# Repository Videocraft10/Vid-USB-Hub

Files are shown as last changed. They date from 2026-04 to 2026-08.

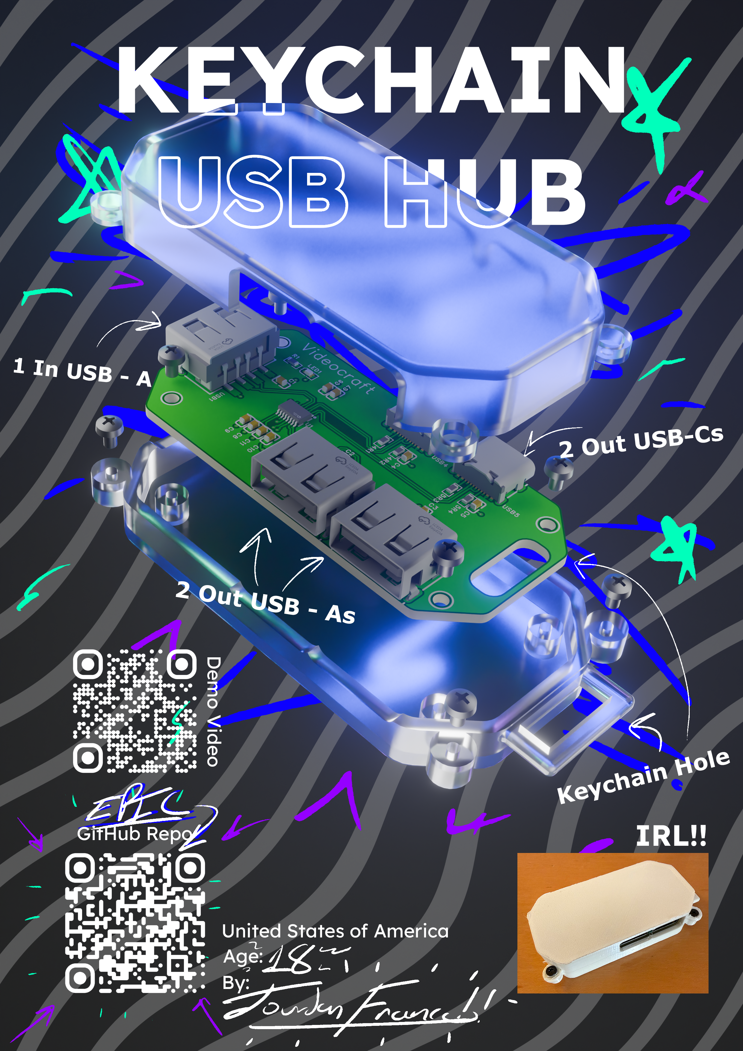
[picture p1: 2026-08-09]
Promo Files/Exports/Videocraft USB Hub v2 Zine BUILD VID.png

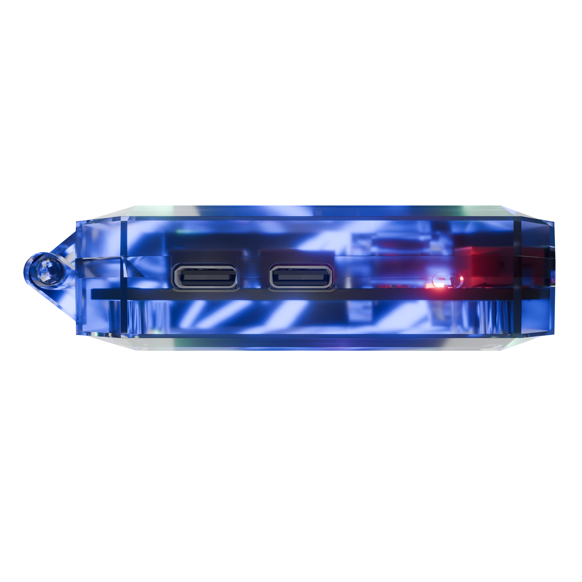
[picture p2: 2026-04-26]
Promo Files/Exports/BigEpicUSBHubMainv2 4k.png

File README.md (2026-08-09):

# USB Hub: Videocraft Edition
USB Hub Main v2
A custom made USB Hub with some cool little features created for Hack Club Fallout.  

*picure above is of v1 case*

## Features
Videocraft USB Hub v2 Zine BUILD VID

1. USB-A Input with 4 output USBs (2 A and 2 C)
2. Cool Keychain hole so you can take your hub around you with style :)
3. Easy to open, 3D printed case so you can admire the PCB
4. Red power LED to indicate when power is flowing though (great to make sure it ain't broke)
5. Secured by 4 easy to remove M2 screws if you want to update the case with a different PCB with the same silhouette

## Why??
I created this project to expand my knowlage on how hardware works on a fundemental level and how it is created, through sourcing materials, and designing the PCB. Additionally I wanted to add my own custom spin on the classic USB Hub by adding some cool fetures that I would appreicate and use.

## The PCB
The PCB for this project was created within EasyEDA for easy parts and footprint integration.

**The Schematic:**


**The Circuit Board:**

Front:


Back:


Picture of the PCB IRL!!



## The Case (v1)
This case was designed using Blender, I choose this over CAD options AT FIRST due to my extensive knowledge and experience in the software.

**Full case**

*This case features a key chain hole and a LED Hole*

**Bottom**



**Top**



**Case open with PCB Inside**

*This case also features a open swinging design to easily open the case though the 3D printed latch to see inside*

## The Case TWO!! (v2)
After designing the case in blender, due to the requirement of having CAD files in the GitHub, I created a second version of the case using Fusion 360!

**Full Case**


**Bottom**


**Top**


**Case with PCB**


**Case Split Up**



## IRL!!




## PCB BOM
*Amount used is for 2 USB Hubs + Price quotes though EasyEDA PCBA*

| Item | JLCPCB # | Single Cost | Amount Used | Fees | Total Price |
| --- | --- | --- | --- | --- | --- |
| 	<ins>USB Hub Chip</ins> | [C2684433](https://jlcpcb.com/partdetail/CoreChips-SL21s/C2684433) | $0.2245 | 2 | Forced to order 5 minimum | $1.1225|
| Resistor 5.1k | [C23186](https://jlcpcb.com/partdetail/23913-0603WAF5101T5E/C23186) | $0.0016 | 8 | None | $0.0128 |
| Capacitors 1uF | [C15849](https://jlcpcb.com/partdetail/16531-CL10A105KB8NNNC/C15849) | $0.0078 | 16 | None | $0.01248 |
| Capacitors 100nF | [C14663](https://jlcpcb.com/partdetail/YAGEO-CC0603KRX7R9BB104/C14663) | $0.003 | 6 | None | $0.018 |
| Power LED | [C2286](https://jlcpcb.com/partdetail/Hubei_KENTOElec-KT0603R/C2286) | $0.0066 | 2 | None | $0.0132 |
| Resistor 330 | [C23138](https://jlcpcb.com/partdetail/23865-0603WAF3300T5E/C23138) | $0.0016 | 2 | None | $0.0032 |
| <ins>Type-A USBs</ins> | [C668591](https://jlcpcb.com/partdetail/SHOUHAN-10_0_QHHTZB63/C668591) | $0.0662 | 6 | Difficult Component Fee + $0.03 per. Plus Order must be a even number, forced to buy 8 (3 for 1 PCB = not even. Forced 4 for one = 8 for both) | $0.5296 |
| <ins>Type-C USBs</ins> | [C2765186](https://jlcpcb.com/partdetail/SHOUHAN-TYPE_C_16PIN_2MD_073/C2765186) | $0.066 | 4 | Forced to buy 5 | $0.33 |
| **PCB Price** | -------- | **PCBA Price + Fees** | **NOTES** | -------- | -------- |
| $2 | -------- | Setup Fee | -------- | -------- | $8.12 |
| -------- | -------- | Stencil | -------- | -------- | $1.52 |
| -------- | -------- | Components | -------- | -------- | $2.15 |
| -------- | -------- | Extended Components Fee | $3.04 per Extended Component (Underlined components are Extended)| -------- | $9.12 |
| -------- | -------- | SMT Assembly | $0.0016 Fee per solder point | -------- | $0.44 |
| -------- | -------- | Special Componet Fee (Type-A USB Difficult fee) | -------- | -------- | $0.24 |
| -------- | -------- | Nitrogen Reflow Soldering | -------- | -------- | $0.85 |
| Total Cost for PCB + 2 PCBA | -------- | -------- | -------- | -------- | $24.44 |
| Shipping Fee | -------- | -------- | -------- | -------- | $9.25 |
| Sales Tax | -------- | -------- | -------- | -------- | $2.23 |
| Grand Total | PCB (5) + PCBA (2) + Shipping + Tax | -------- | -------- | -------- | $35.92 |

## Build BOM

| Item | Discripton | Notes | Cost/Amount Used |
| --- | --- | --- | --- |
| 3D Printer PLA | Generic 3D printer PLA. Requires a 3D printer to use | Paid $8.34 for 1 kg | Aproxx 14g of filament = $0.12 |
| M2 x 3mm Screws | -------- | 4 Required for case v1, 8 required for case v2 | $4.28 [here](https://www.amazon.com/gp/product/B0B1Q9QQ7F?smid=A1BQWGBLWM4VYT&th=1) | 
| ---------- | ---------- | ---------- | ---------- | ---------- | ---------- |
| Total | ---------- | ---------- | ---------- | ---------- | $4.40 |

***GRAND TOTAL*** = $40.32

## How to use!
Pretty simple! Plug in a device, like a phone or computer, and you can now plug four USB accessoies though that one USB port!

## How to make one yourself!
*If you have no intention of modifying the case or PCB and you have a 3D printer, here are the steps to follow:*

1. Download your preferred case from the [Ready to Print](https://github.com/Videocraft10/Vid-USB-Hub/tree/main/Case%20Files/Ready%20to%20Print%20Files) folder. Please note that the only case that is 100% polished and updated will always be [V2 Case Files](https://github.com/Videocraft10/Vid-USB-Hub/tree/main/Case%20Files/Ready%20to%20Print%20Files/V2%20Case%20Files) Once downloaded (click the download button on the top right), open it in your 3D printer slicer of choice and export. I will be printing in a generic PLA on an Ender 3 Pro 3D printer, using the Super Quality preset, with tree supports enabled in the Cura Slicer settings.
2. Once you have the 3D print going, download the EasyEDA PCB files from the [PCB](https://github.com/Videocraft10/Vid-USB-Hub/tree/main/PCB%20Files) folder in the GitHub. Please note that EasyEDA files are not supported on KiCad, but you might be able to get them to work with some workarounds if you really want to.
3. Import to EasyEDA and click Order.
4. It is recommended to select the PCB Assembly option to get it pre-assembled. I recommend getting 2 assembled.
6. There you go! Once your PCB arrives, smack it into the case and secure it with M2 screws in the 4 corners. (if you did case v2 then also secure the case shut with 4 more m2 screws!)
7. You are now a proud owner of the Videocraft USB Hub :)
P.S. If you dont want to use EasyEDA I have also included the Garber File export too! You can find it [here!](https://github.com/Videocraft10/Vid-USB-Hub/blob/main/PCB%20Files/Gerber_VidUSBHUB.zip)

*If you **DO** have intentions of modifying the case or PCB, here are the steps to follow:*
1. All Blender files, including promotional files, are [here](https://github.com/Videocraft10/Vid-USB-Hub/tree/main/Promo%20Files).
2. Blender files were created in Blender 5.1.1.
3. CAD Files are ONLY avalable for Case v2 (closed, no opening mechanism)
4. CAD Files where created in Fusion 360, with .f3z .obj and .step files avalable
5. CAD files are located [here](https://github.com/Videocraft10/Vid-USB-Hub/tree/main/Case%20Files/CAD%20Files%20(v2))
6. Download the EasyEDA files from above in the [PCB](https://github.com/Videocraft10/Vid-USB-Hub/tree/main/PCB%20Files) folder in the GitHub.
7. Import into EasyEDA and modify to your heart's content!

## Software Used
1. EasyEDA
2. Blender
3. Autodesk Fusion
4. Adobe Photoshop
5. Adobe Premiere Pro

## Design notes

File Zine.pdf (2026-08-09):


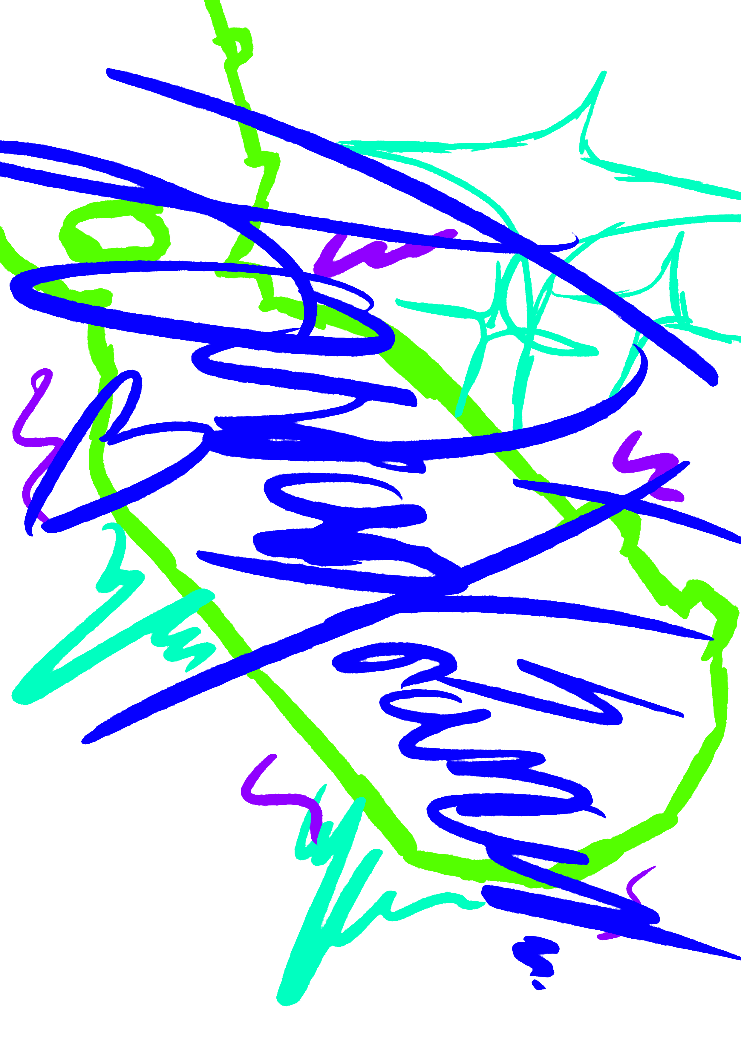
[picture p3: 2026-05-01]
Promo Files/Exports/Videocraft USB Hub Zine Grafiti.png

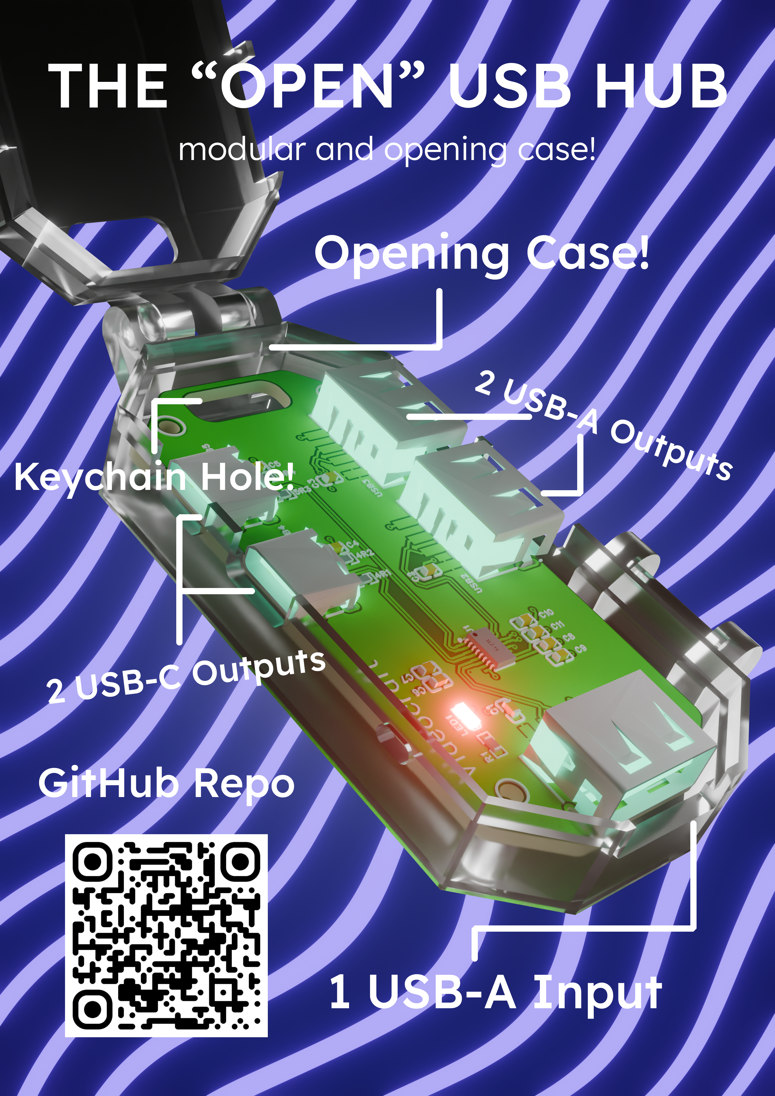
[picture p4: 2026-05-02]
Promo Files/Exports/Videocraft USB Hub Zine v2.png

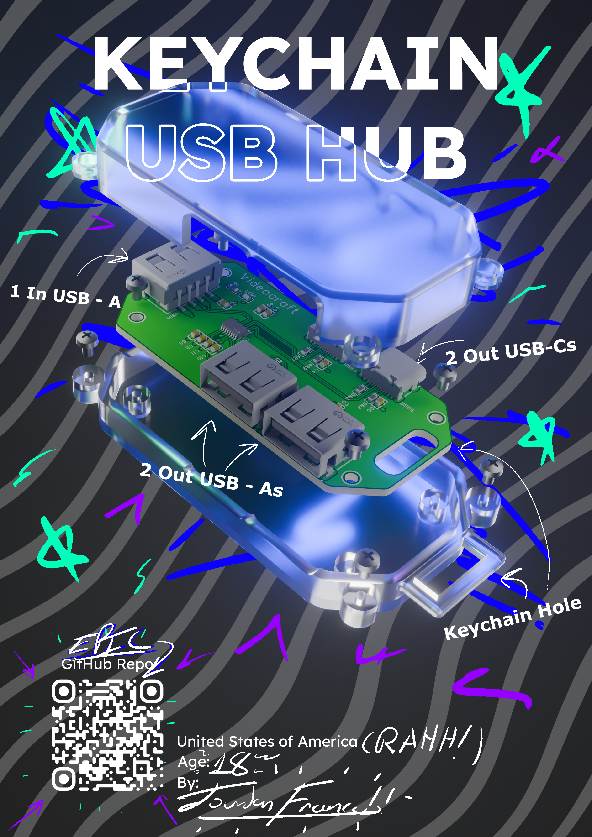
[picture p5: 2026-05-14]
Promo Files/Exports/Videocraft USB Hub Zine v5.png

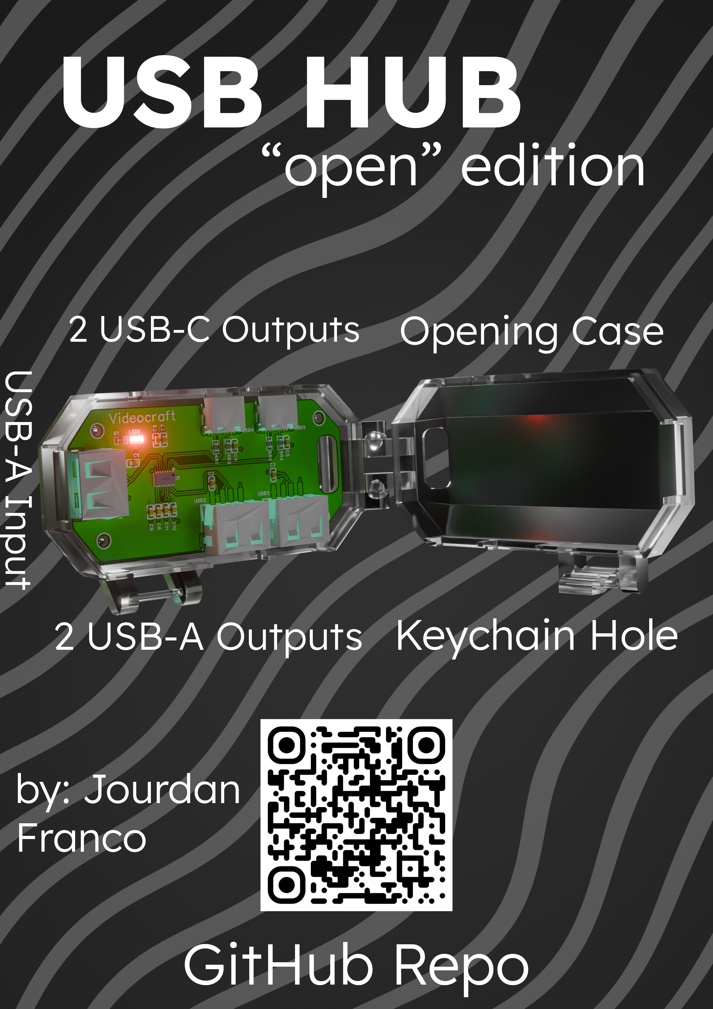
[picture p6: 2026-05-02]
Promo Files/Exports/Videocraft USB Hub Zine v3.png

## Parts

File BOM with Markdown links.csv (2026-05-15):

PCB BOM
Item | JLCPCB # | Single Cost | Amount Used | Fees | Total Price
USB Hub Chip | [C2684433](https://jlcpcb.com/partdetail/CoreChips-SL21s/C2684433) | $0.22 | 2 | Forced to order 5 minimum | $1.12
Resistor 5.1k | [C23186](https://jlcpcb.com/partdetail/23913-0603WAF5101T5E/C23186) | $0.00 | 8 | None | $0.01
Capacitors 1uF | [C15849](https://jlcpcb.com/partdetail/16531-CL10A105KB8NNNC/C15849) | $0.01 | 16 | None | $0.01
Capacitors 100nF | [C14663](https://jlcpcb.com/partdetail/YAGEO-CC0603KRX7R9BB104/C14663) | $0.00 | 6 | None | $0.02
Power LED | [C2286](https://jlcpcb.com/partdetail/Hubei_KENTOElec-KT0603R/C2286) | $0.01 | 2 | None | $0.01
Resistor 330 | [C23138](https://jlcpcb.com/partdetail/23865-0603WAF3300T5E/C23138) | $0.00 | 2 | None | $0.00
Type-A USBs | [C668591](https://jlcpcb.com/partdetail/SHOUHAN-10_0_QHHTZB63/C668591) | $0.07 | 6 | Difficult Component Fee + $0.03 per. Plus Order must be a even number, forced to buy 8 (3 for 1 PCB = not even. Forced 4 for one = 8 for both) | $0.53
Type-C USBs | [C2765186](https://jlcpcb.com/partdetail/SHOUHAN-TYPE_C_16PIN_2MD_073/C2765186) | $0.07 | 4 | Forced to buy 5 | $0.33
PCB Price |  | PCBA Price + Fees | NOTES
$2 |  | Setup Fee |  |  | $8.12
 |  | Stencil |  |  | $1.52
 |  | Components |  |  | $2.15
 |  | Extended Components Fee | $3.04 per Extended Component (Underlined components are Extended) |  | $9.12
 |  | SMT Assembly | $0.0016 Fee per solder point |  | $0.44
 |  | Special Componet Fee (Type-A USB Difficult fee) |  |  | $0.24
 |  | Nitrogen Reflow Soldering |  |  | $0.85
Total Cost for PCB + 2 PCBA |  |  |  |  | $24.44
Shipping Fee |  |  |  |  | $9.25
Sales Tax |  |  |  |  | $2.23
Grand Total | PCB (5) + PCBA (2) + Shipping + Tax |  |  |  | $35.92
## Build BOM [WIP]
Item | Discripton | Notes | Cost/Amount Used
3D Printer PLA | Generic 3D printer PLA. Requires a 3D printer to use | Paid $8.34 for 1 kg | Aproxx 14g of filament = $0.12
M2 x 3mm Screws |  | 4 Required for case v1, 8 required for case v2 | [$0.80](https://www.moddiy.com/products/1262/M2.0-x-3mm-Black-Screws-CM2X3X4.html)

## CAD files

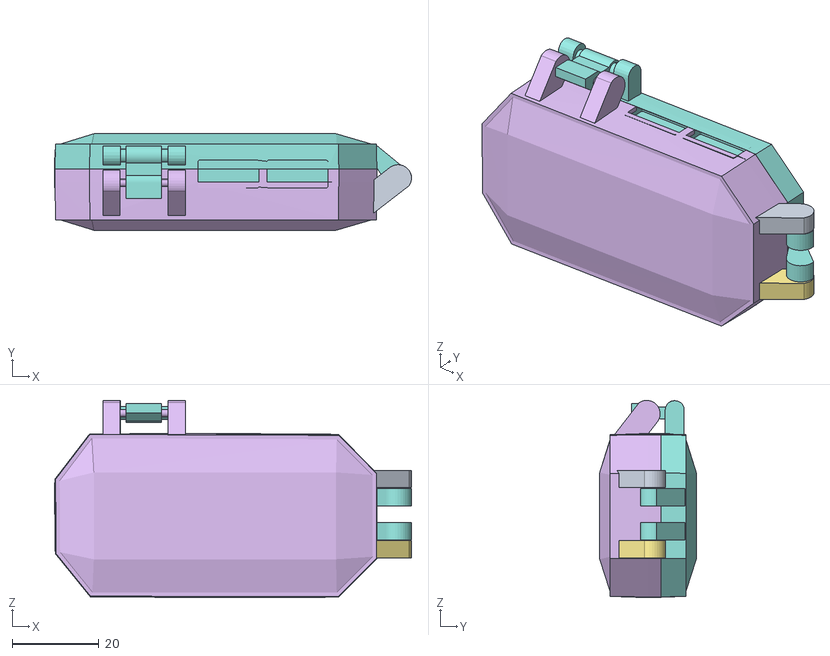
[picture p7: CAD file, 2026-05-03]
Case Files/Blender Files (v0)/Videocraft USB Hub v0 Case All Componets.obj
82.2 x 22.2 x 45.4
VidUSBHubv0
Scew
Scew.001
Scew.002
Scew.003
CaseBot
LatchR.001
LatchL.002
LatchR.002

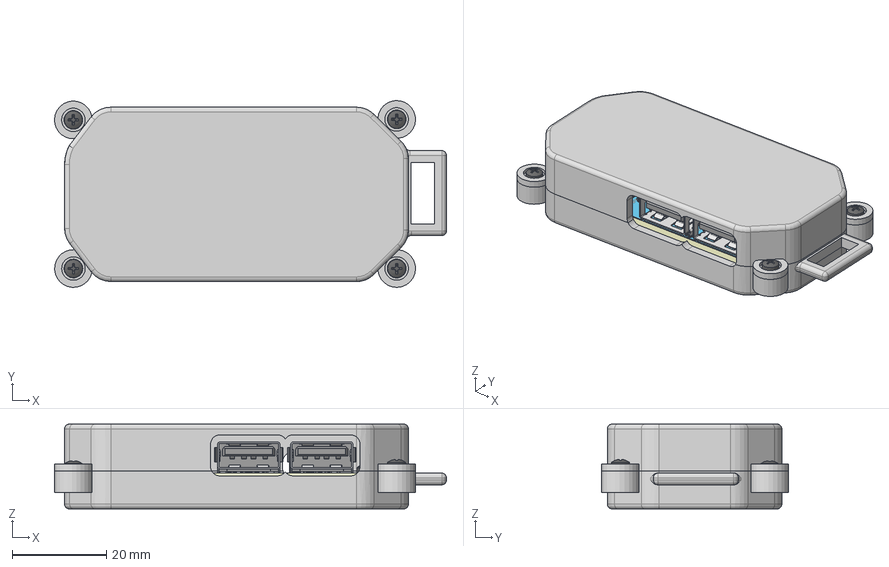
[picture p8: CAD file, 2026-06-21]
Case Files/CAD Files (v2)/Videocraft USB Hub v2 CAD.step
83.1 x 39.6 x 18.0 mm
DIN 7985 - M2x3-H H Steel 4.6 Zinc x 7
DIN 7985 - M2x3-H H Steel 4.6 Plain

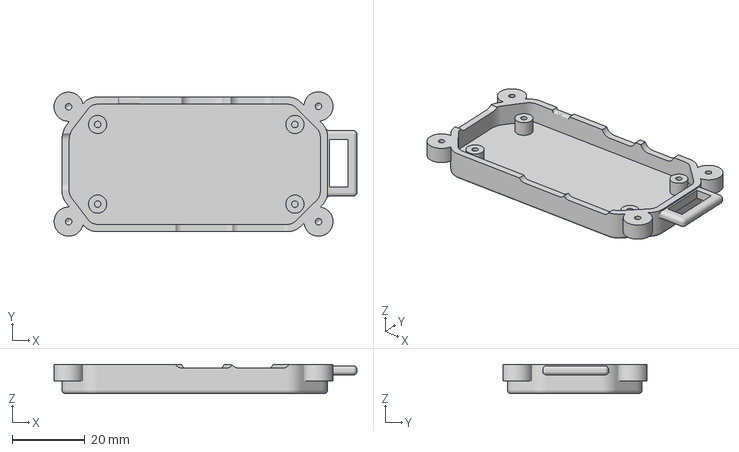
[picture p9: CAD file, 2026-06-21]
Case Files/Ready to Print Files/V2 Case Files/Closed Videocraft USB Case Bottom v2.3mf
83.1 x 39.6 x 8.00 mm

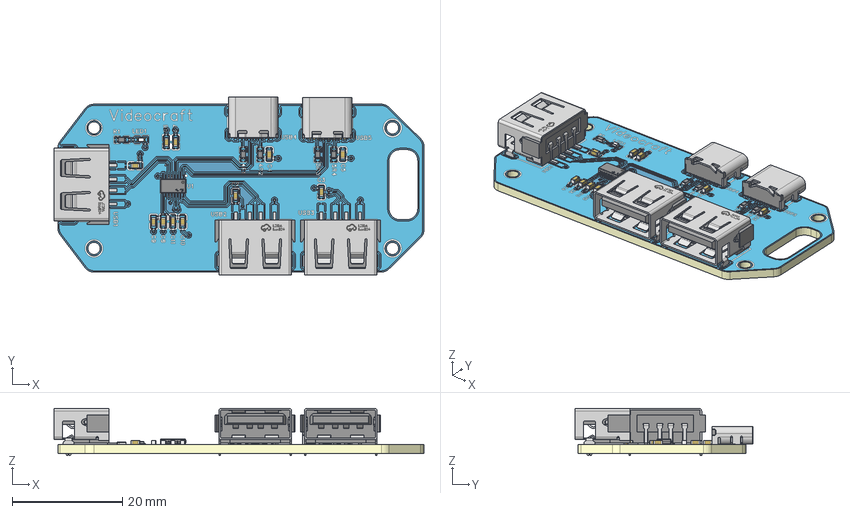
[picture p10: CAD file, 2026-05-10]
PCB Files/Videocraft USB Hub CAD PCB.step
67.1 x 32.3 x 8.60 mm
Board~aYtN
TopCopper~aYtN
BottomCopper~aYtN
TopSilkscreen~aYtN
BottomSilkscreen~aYtN
TopFpcStiffener~aYtN
BottomFpcStiffener~aYtN
LED0603-RD~LED0603-RD~aYtN
R0603~R0603~aYtN x 5
C0603~C0603_L1.6-W0.8-H0.8~aYtN x 11
USB-C-SMD_TYPE-C-6PIN-2MD-073~USB-C-SMD_TYPE-C-6PIN-2MD-073~aYtN x 2
SSOP-16_L4.6-W2.6-P0.53-LS4.0-BL~SSOP-16_L4.6-W2.6-P0.53-LS4.0-BL~aYtN
USB-A-TH_10.0QHHTZB6.3~USB-A-TH_10.0QHHTZB6.3~aYtN x 3

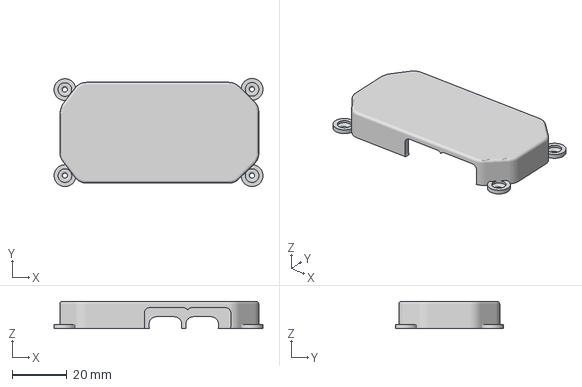
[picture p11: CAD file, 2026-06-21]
Case Files/Ready to Print Files/V2 Case Files/Closed Videocraft USB Case Top v2.3mf
76.5 x 39.6 x 10.0 mm

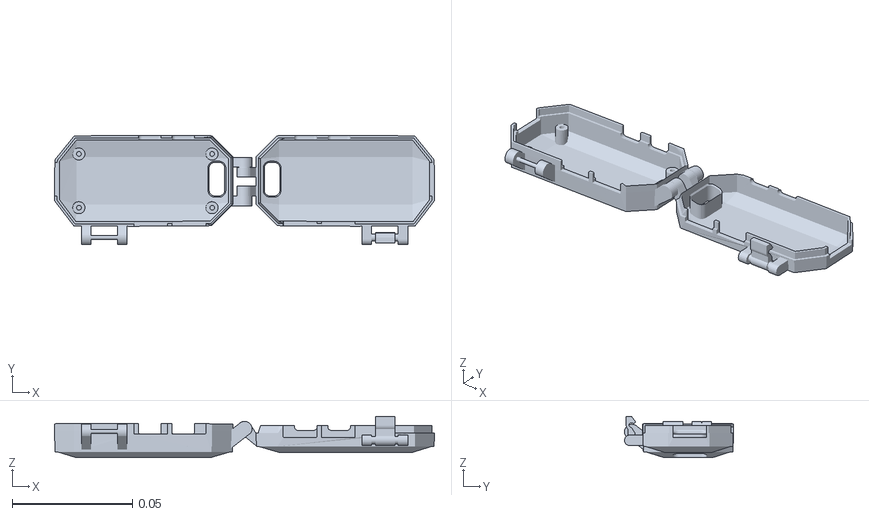
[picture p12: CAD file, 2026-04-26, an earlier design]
Case Files/Ready to Print Files/V0 Case Files/Videocraft USB Hub v0 Case Keyhole_Print.stl
0.158 x 0.0454 x 0.0172

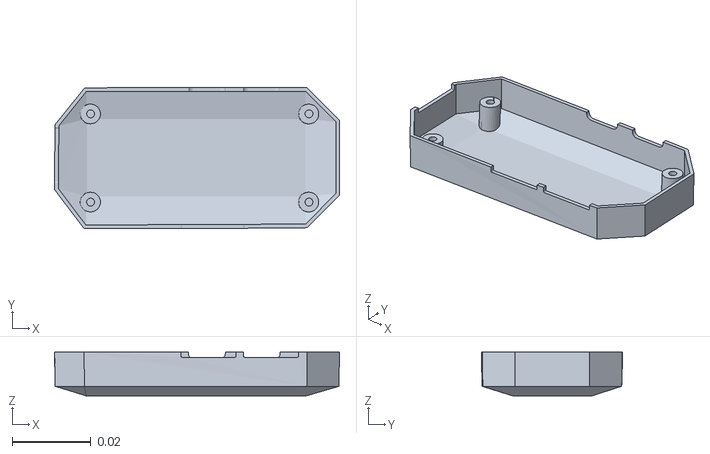
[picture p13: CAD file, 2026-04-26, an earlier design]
Case Files/Ready to Print Files/V0 Case Files/NO LATCH Bottom Videocraft USB Hub v0 Case.stl
0.0723 x 0.0358 x 0.0111

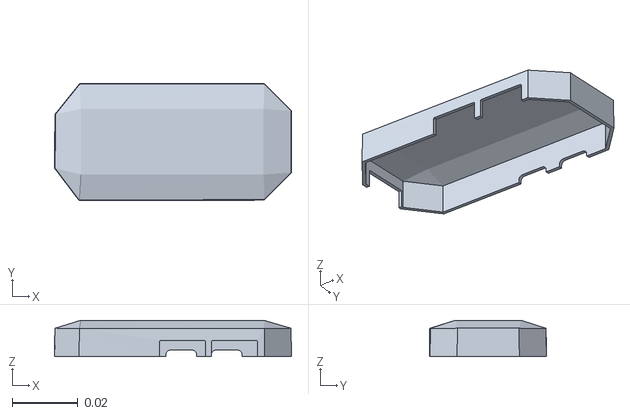
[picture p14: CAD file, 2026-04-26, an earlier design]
Case Files/Ready to Print Files/V0 Case Files/NO LATCH Top Videocraft USB Hub v0 Case.stl
0.0723 x 0.0358 x 0.0111

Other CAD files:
Case Files/Ready to Print Files/V0 Case Files/Videocraft USB Hub v0 Case_Print.stl
Case Files/Ready to Print Files/V0 Case Files/Videocraft USB Hub v0 Case Keyhole+LED Hole_Print.stl
Case Files/Blender Files (v0)/Videocraft USB Hub v0 Case All Componets.blend
Case Files/Blender Files (v0)/Videocraft USB Hub v0 Case Pre Lock.blend
Case Files/Blender Files (v0)/Videocraft USB Hub v0 Case Print Ready Keyhole.blend
Case Files/Blender Files (v0)/Videocraft USB Hub v0 Case.blend
Case Files/CAD Files (v2)/Videocraft USB Hub v2 CAD.f3z
Case Files/CAD Files (v2)/Videocraft USB Hub v2 CAD.obj
Promo Files/Blender Files/Backgound.blend
Promo Files/Blender Files/Videocraft USB Hub v0 Case Promo Zine View 2.blend
Promo Files/Blender Files/Videocraft USB Hub v0 Case Promo Zine View 3.blend
Promo Files/Blender Files/Videocraft USB Hub v0 Case Promo Zine View 4.blend
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

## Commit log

2026-04-25 Add BOM section with component costs and details
    Added Bill of Materials (BOM) for USB Hub components and pricing details.
2026-04-25 Revise README with features and BOM details
    Updated the README to enhance the description and add features and BOM sections.
2026-04-26 Expand README with project details and instructions
    Added sections on project motivation, PCB details, case design, and BOM for creating a USB hub.
2026-04-26 Added Development Files
    [NO LATCH Bottom Videocraft USB Hub v0 Case (2).stl, NO LATCH Top Videocraft USB Hub v0 Case (1).stl, Videocraft USB Hub v0 Case Keyhole+LED Hole_Print.stl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]
2026-04-26 Update README with DIY instructions for USB Hub
    Added detailed instructions for creating the Videocraft USB Hub, including 3D printing and PCB assembly steps.
2026-04-27 Fix typos and enhance clarity in README instructions
    Correct typos and improve clarity in instructions for 3D printing and PCB assembly.
2026-04-27 Added BOM CSV file
    [Videocraft_USB_Hub_BOM.csv]
2026-04-27 Reorganized folders
    [NO LATCH Bottom Videocraft USB Hub v0 Case (2).stl, NO LATCH Top Videocraft USB Hub v0 Case (1).stl, Videocraft USB Hub v0 Case Keyhole+LED Hole_Print.stl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]
2026-04-29 Fix links and update folder names in README
    Updated links and folder names for case and PCB files in the README.
2026-05-01 Zine Work
    [Backgound.blend, Videocraft USB Hub v0 Case Promo Zine.blend]
2026-05-02 Created more zine prototypes
    [Videocraft USB Hub v0 Case Promo Zine View 2.blend, Videocraft USB Hub v0 Case Promo Zine.blend]
2026-05-03 MORE ZINEEEE
    [Videocraft USB Hub v0 Case All Componets.obj, Videocraft USB Hub v0 Case Promo Zine View 3.blend, Videocraft USB Hub v0 Case Promo Zine View 4.blend]
2026-05-10 Added the CAD Case files v2!
    Also changed some names and organized folders
    Will update README hyperlinks soon
    [Closed Videocraft USB Case Bottom v2.3mf, Closed Videocraft USB Case Top v2.3mf, NO LATCH Bottom Videocraft USB Hub v0 Case.stl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]
2026-05-10 Created v2 Zine Files
    also organized more
    [Closed Videocraft USB Case Bottom v2.3mf, Closed Videocraft USB Case Top v2.3mf, NO LATCH Bottom Videocraft USB Hub v0 Case.stl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]
2026-05-12 Tweaked screw holes and added screw mesh to holes
    [Closed Videocraft USB Case Bottom v2.3mf, Closed Videocraft USB Case Top v2.3mf, Videocraft USB Hub v2 CAD.f3z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]
2026-05-12 Zine work with v2 case
    [Videocraft USB Hub v2 Case Promo Zine.blend]
2026-05-14 Final Zine!
    [Videocraft USB Hub v2 Case Promo Zine.blend]
2026-05-14 Update CAD files
    LED hole was hidden
    [Closed Videocraft USB Case Bottom v2.3mf, Closed Videocraft USB Case Top v2.3mf, Videocraft USB Hub v2 CAD.f3z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]
2026-05-14 THE FINAL README
    Added images and updated instructions for case design.
2026-05-15 Revise README with BOM updates and usage instructions
    Updated the BOM with links and improved descriptions. Added a section on how to use the USB hub and instructions for building it.
2026-05-15 Revise case design section in README
    Updated the section about the case design to include versioning and clarify initial software choice.
2026-05-15 updated BOM
    [Videocraft USB Hub BOM.csv]
2026-05-15 Added BOM with markdown links
    [BOM with Markdown links.csv, Videocraft USB BOM Excel.xlsx, Videocraft USB Hub v2 Case Promo Zine.blend]
2026-05-15 Add PCB IRL image to README
    Added an additional image of the PCB to the README.
2026-06-05 Update M2 x 3mm screws cost and link
    Updated the cost link for M2 x 3mm screws to a new Amazon source.
2026-06-05 Revise BOM section with updated screw pricing
    Updated pricing for M2 x 3mm screws and added total cost to BOM section.
2026-06-21 built irl and updated zine
    [Closed Videocraft USB Case Bottom v2.3mf, Closed Videocraft USB Case Top v2.3mf, Videocraft USB Hub v2 CAD.f3z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]
